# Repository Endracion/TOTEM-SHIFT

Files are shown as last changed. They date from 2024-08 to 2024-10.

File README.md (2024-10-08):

<picture align="center">
  <source media="(prefers-color-scheme: dark)" srcset="/docs/images/TOTEM_logo_dark.svg">
  <source media="(prefers-color-scheme: light)" srcset="/docs/images/TOTEM_logo_bright.svg">
  TOTEM logo
</picture>

<h1 align="center">T O T E M - S H I F T</h1>

TOTEM-SHIFT is a modified 38 keys column-staggered split keyboard originally by GEIGEIGEIST.

This TOTEM-SHIFT version aims to allow for a larger battery and emphasize styling options through a swappable top plate held with magnets ([demo](https://www.youtube.com/watch?v=WX03MpgzbRs)). Meant to be used with a SEEED XIAO BLE (no longer supports the RP2040 with the TRRS port removed) for a wireless only build.

**WHY** a swappable top plate? Well I'm sure everyone has asked themselves at least once, which case should I go for? And then you're half locked into it.
I want to be able to change my mind, to change colors, logos, motifs or other surface effects to go with the style I want that day, so why not allow myself to do just that with a swappable top plate!

It was created for the SEEED XIAO keyboard contest by GEIGEIGEIST.\
[Here](https://www.hackster.io/geist/totem-a-tiny-splitkeyboard-with-splay-cb2e43) you can read about the process of making it.

Note that most of the guides and links will remain unchanged, the major changes will be to the 3D printed case design, as it uses the [TOTOEM Redux by VOID](https://www.printables.com/model/840146-totem-redux) case files as base, which are better suited to FDM 3D printing.

> **Note**
> The PCB is modified enought that this version will not be compatible with existing PCBs or cases for the original TOTEM.

***

## LAYOUT

TOTEM layout

***

## PCB

[Here](/PCB/TOTEM-SHIFT%200.4) you can find the KiCad files and Gerbers for the TOTEM.

Gerber files to upload for production are found [here](https://github.com/Endracion/TOTEM-SHIFT/tree/main/PCB/TOTEM-SHIFT%200.4/production).

***

## CASE

You can use the TOTEM without a case, but [here](https://www.printables.com/model/1033457-totem-shift-wireless-ble-redux-split-splay-keyboar) is the FDM 3D printed case I designed for it.

***

## BUILD GUIDE
  
The build guide for the TOTEM can be found [here](/docs/buildguide.md).

***

## FIRMWARE

[ZMK config](https://github.com/Endracion/zmk-config-totem-shift) for the TOTEM (wireless using the XIAO BLE)

The dongle version is coming at a later time.

***

## PHOTOS

This is the 3D printed TOTEM-SHIFT BLE Redux case with the MOTE keycaps.

This is the TOTEM in a black resin case

TOTEM black resin\
TOTEM black resin\
TOTEM black resin

***

## BUY 

If there is enough interest, I may do a production run for this modified version, please feel free to reach out.

***

## CREDITS

### ORIGINAL CREATOR

The amazing [GEIGEIGEIST](https://github.com/GEIGEIGEIST) whose design are beautiful and inspiring.
VOID who created a FDM optimized case [TOTOEM Redux](https://www.printables.com/model/840146-totem-redux).
eiga for the [MOTE keycaps]{https://www.printables.com/model/864126-mote-choc-low-profile-flat-keycaps}.

### INSPIRATION

The additional pinky key makes the TOTEM compatible with the layout boards like the [Balbuzard](https://github.com/brow/balbuzard) by [Tom Brow](https://github.com/brow) and the [Osprette](https://github.com/smores56/osprette) by [Sam Mohr](https://github.com/smores56) use, where you put the keybinding of the top left and right keys on an outer pinky key.

### HELP FIXING THINGS

People who helped GEIGEIGEIST create this board and fix stuff:

#### PCB
- [Marco "Bob"](https://github.com/GroooveBob)

#### CASE
- [Freya](https://github.com/freya-irl)
- [Bubbleology](https://github.com/bubbleology)

#### FIRMWARE
- [Cem Aksoylar](https://github.com/caksoylar)
- [Grinnie](https://github.com/regicidalplutophage)
- [Alaa Saad Mansour](https://github.com/AlaaSaadAbdo)
- [pekudzu](https://github.com/pekudzu)

If you build a TOTEM, GEIGEIGEIST would be pretty happy to see some pictures. And if you want to leave him a tip you can do so [here](https://ko-fi.com/geigeigeist) (but please don't feel pressured)

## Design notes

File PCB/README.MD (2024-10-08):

# TOTEM-SHIFT PCB FILES

I have modified the original PCB extensively, so here is a list of the largest changes:
- Moved the middle finger column down by approx 2.3mm, as it felt a little high compared to other boards.
- Made the underside of the XIAO easier to solder through a larger cutout.
- Moved the battery contact points above the diodes for the larger size battery cavity.
- Moved the diodes to the rear to make a little more space for the battery and for a clean top PCB.
- Rerouted many traces, cleaned up others and added many diagonal angles for aesthetic purposes and to remove acute angles which are more prone to manufacturing errors.
- Removed the TRRS connector completely as this is a wireless-centric design now.
- Replaced the reset and power switches with hidden ones inside of the top plate, where the TRRS used to be. This gives the case a completely clean look.
- Removed the large color silkscreens as while they were super nice, it was not possible for me to edit them in a way that looked good since I don't have the source files.
- Moved a few other things to make place for these changes.
- Tried to realign one of the holes on the right as it wasn't mirrored properly.
- Everything has been updatd for KiCad 8.0 and gerber files should be able to be easily uploaded to PCB manufacturer websites, I've provided my gerber zip file prepared by JLCPCB's plugin.

> **Note**
> As a reminder: The PCB is modified enought that this version will not be compatible with existing PCBs or cases for the original TOTEM.

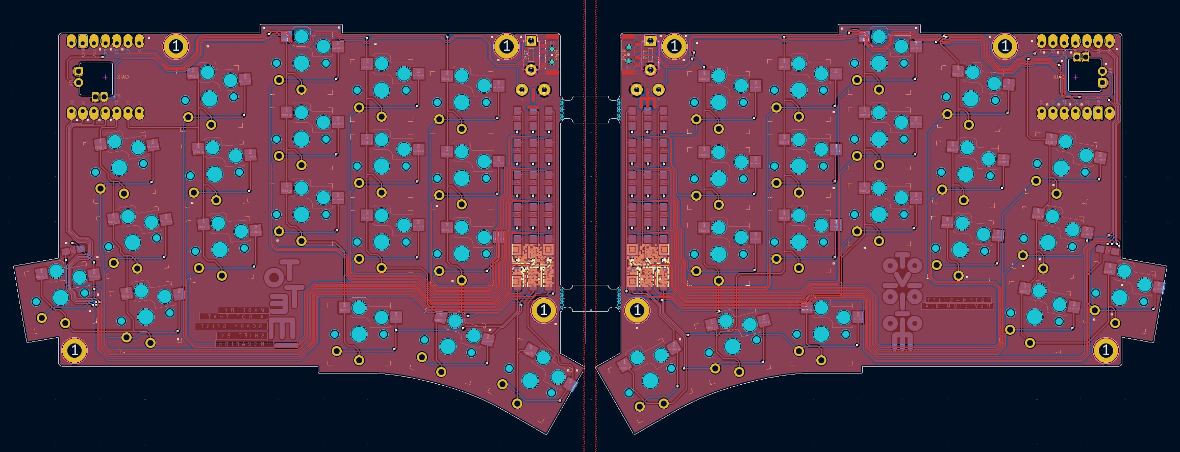
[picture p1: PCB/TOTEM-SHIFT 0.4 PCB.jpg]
TOTEM PCB


# TOTEM-SHIFT FUTURE

What I'm thinking of working on next after this build is complete and I'm satisfied using it.

- [ ] Utilize additional pins from NFC/Sense for ?
- [ ] Implement support for LCD on the board or on the dongle (for layer visibility and style)
- [ ] Implement support for encoder
- [ ] Implement support for pointing device (touchpad, trackpad, mini trackball)
- [ ] Recreate a similar board from scratch that's fully reversible

# TOTEM PCB FILES

## MANUFACTURING
If you want to get the PCB made you need to download the [ZIP](/PCB/totem_0-3/totem_0-3_gerbers.zip/) and upload it to the website of the manufacture 
I can recommend [JLCPCB](https://jlcpcb.com/), [Seeed Fusion](https://www.seeedstudio.com/fusion_pcb.html) or [PCBway](https://www.pcbway.com/).

- Download [the ZIP file](/PCB/TOTEM-SHIFT%200.4/production/TOTEM-SHIFT_split_keyboard_0.4.zip)
- Upload the ZIP file to the website of the manufacturer.
- Sometimes the Gerber preview from JLCPCB can't display the PCB, even when the files are fine. In this case use these dimensions: 258.7mm * 94.35mm.
- PCB Thickness: 1.6mm
- Layers: 2
- Different designs: 2 (because both halves are not the same).
- PCB Qty as much as you like, but minimum is always 5. One PCB is a full keyboard.
- PCB Color Black (or any other color you like).
- No impedance control.
- Surface Finish HASL (with lead) if you want the easiest soldering experience or LeadFree HASL.
- Remove Order Number: Yes

TOTEM PCB

***

## CHECK PINOUT OR TRACES

If you only want to check the traces or see what is connected to which pin you can take a look at these graphics.
You can also take a look at the [schematics](TOTEM_0-3_schematics.pdf) and the [PCB](TOTEM_0-3_PCB.pdf) as PDF.

TOTEM pinout

***

TOTEM traces

***

## TAKE A DEEPER LOOK OR MODIFY 

You can download the project if you need to take a deeper look or modify something. You need the Open Source software [KiCad](https://www.kicad.org/) to open it.

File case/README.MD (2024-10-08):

# TOTEM-SHIFT BLE REDUX CASE

These files can be found on Printables: [TOTEM-SHIFT Wireless BLE Redux Case](https://www.printables.com/model/1033457-totem-shift-wireless-ble-redux-split-splay-keyboar).
I've paired with the [MOTE](https://www.printables.com/model/864126-mote-choc-low-profile-flat-keycaps) keycaps and the [15 degree remix](https://www.printables.com/model/1000549-mote-remixed-choc-low-profile-flat-keycaps-with-mo) for more of a keywell feel.

I remixed the excellent [Totem Redux](https://www.printables.com/model/840146-totem-redux) by VOID and drew inspiration from BeeKeeb's rendition as well.
This case is made to be printed on an FDM printer, though it may work just fine on resin as well, I have not tested it.

My changes are as follows:
- Larger cavity above the diode area to accommodate a larger battery up to approx 7x15x42mm with capacities up to ~180 mAh.
- Removed all holes from the top cover in order to make it look cleaner and allow for future design choices (multi color motifs coming soon).
- Replaced these top screw holes with recessed magnet holes and crush tabs (so they're press fit) so that it can be magnetically attached and swapped ([demo](https://www.youtube.com/watch?v=WX03MpgzbRs)).
- Removed the countersink from the bottom plate so that the midplate is screwed into the bottom plate and acts as the magnet retention mechanism, along with the recessed feet holes as it won't print well on FDM.
- Removed the need for standoffs, everything screws or is pushed directly into the plastic for a tight fit.
- Removed all side holes except USB-C port since the TRRS port is removed and the reset and power switches are now hidden under the top cover.
- Adjusted many small parts of the assembly and redrew the bottom case to make FDM printing easier.
- Adjusted part heights to match 0.2 mm printing layer height and so that the midplate is the correct height to attach the switches to it and not create additional flexing.

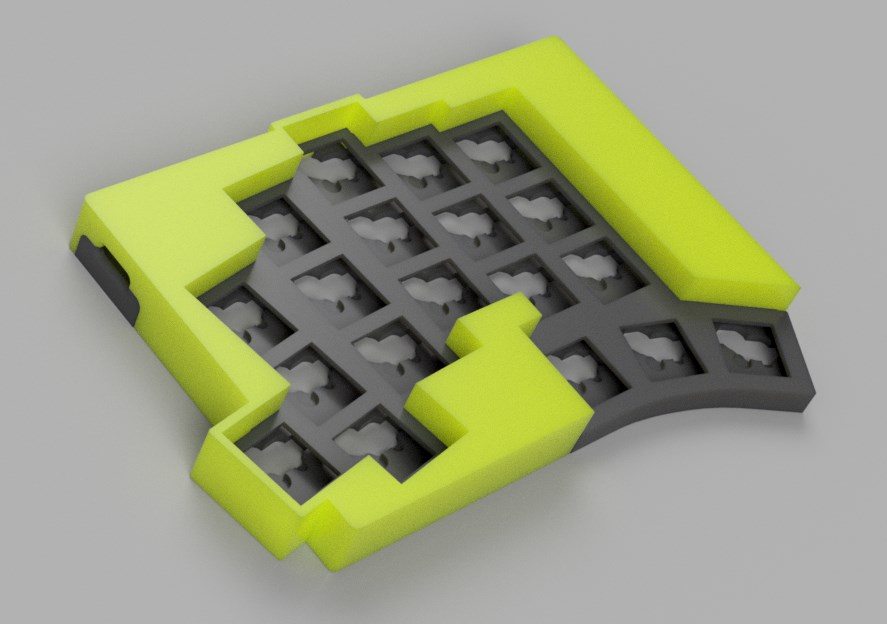
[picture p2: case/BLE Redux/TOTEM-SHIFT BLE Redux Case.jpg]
TOTEM-SHIFT BLE Redux case


# ORIGINAL TOTEM CASE

Each half consists of a bottom and a top part (with an integrated switchplate) and is meant to be 3D printed in resin. 

I got good results from [JLCPCB](https://cart.jlcpcb.com/quote) (15€ + tax and shipping for a black or white version) and [PCBway](https://www.pcbway.com/rapid-prototyping/manufacture/?type=2&reffercode=TOP) (50€ + tax and shipping for a clear case).

Where possible use the STEP files, but the STL files should be fine too.

If you're sure you only will use the wired version you can also use the case without a power switch (USB) or use the case without a TRRS cutout if you plan on using the wireless version (BLE).

> **Note**
> The manufacturer will probably warn you about too thin sections, but it worked fine for me since these sections are pretty small.

TOTEM case

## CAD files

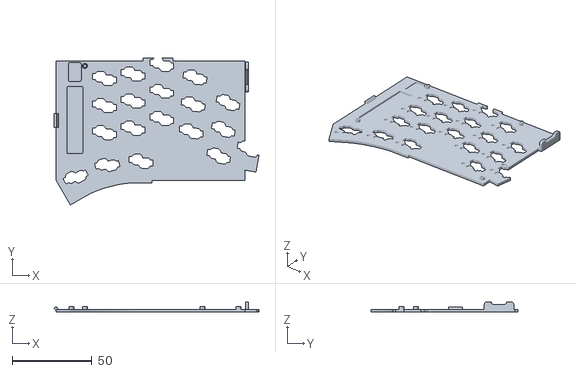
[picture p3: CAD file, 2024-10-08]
case/BLE Redux/TOTEM-SHIFT Right Bottom.stl
128.7 x 92.3 x 6.50

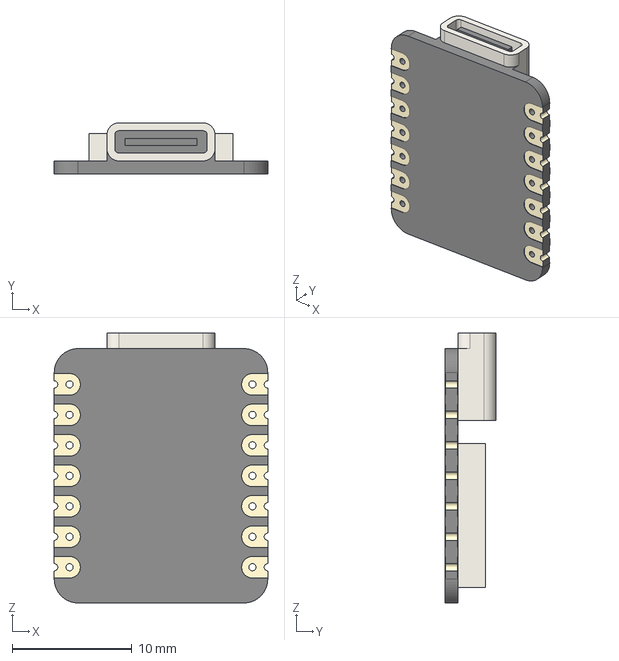
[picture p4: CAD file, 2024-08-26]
PCB/TOTEM-SHIFT 0.4/TOTEM3D/xiao-ble-tht.step
17.8 x 4.27 x 22.5 mm

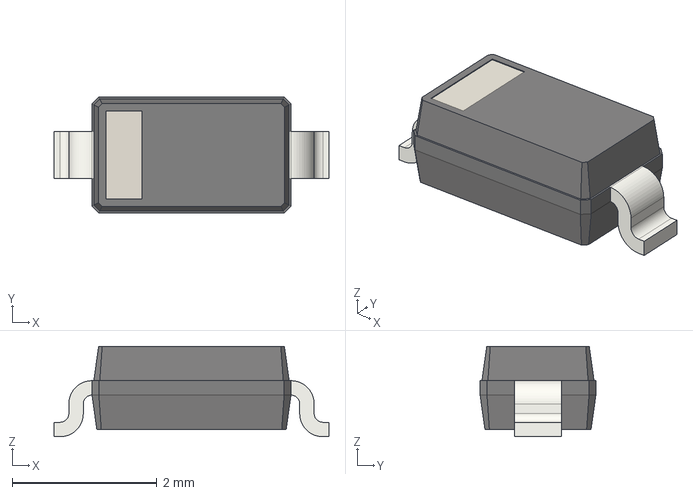
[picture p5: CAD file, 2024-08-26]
PCB/TOTEM-SHIFT 0.4/TOTEM3D/D_SOD-123.step
3.80 x 1.60 x 1.25 mm

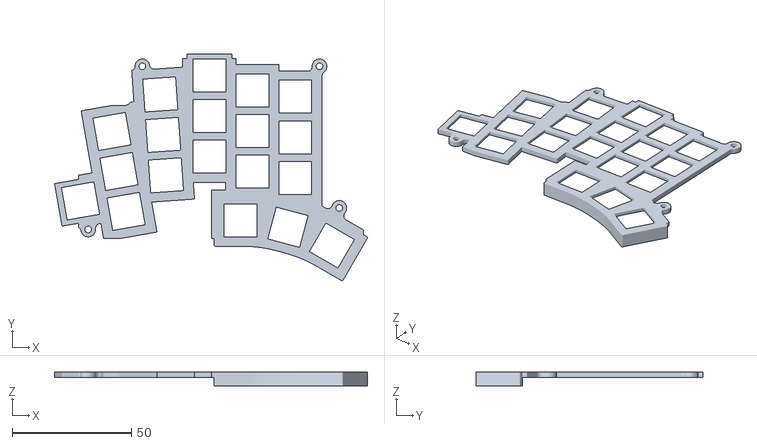
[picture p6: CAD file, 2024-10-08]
case/BLE Redux/TOTEM-SHIFT Left Midplate.stl
131.1 x 94.9 x 5.80

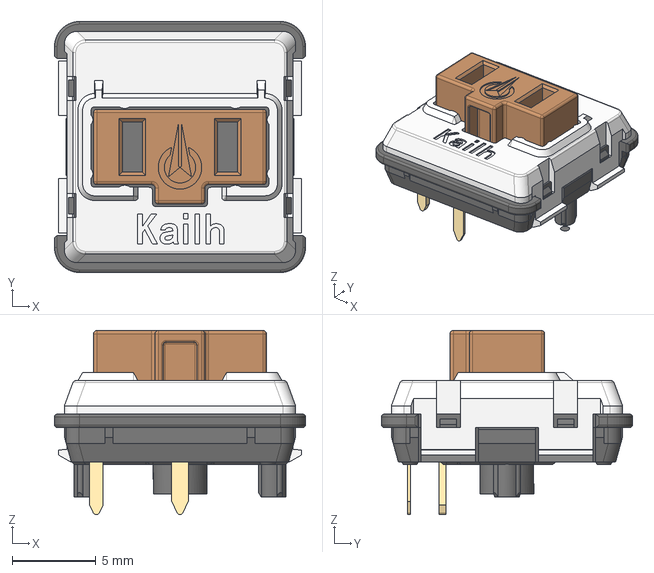
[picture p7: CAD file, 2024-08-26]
PCB/TOTEM-SHIFT 0.4/TOTEM3D/Kailh_switch_PG1350_optional.step
15.0 x 15.0 x 11.0 mm

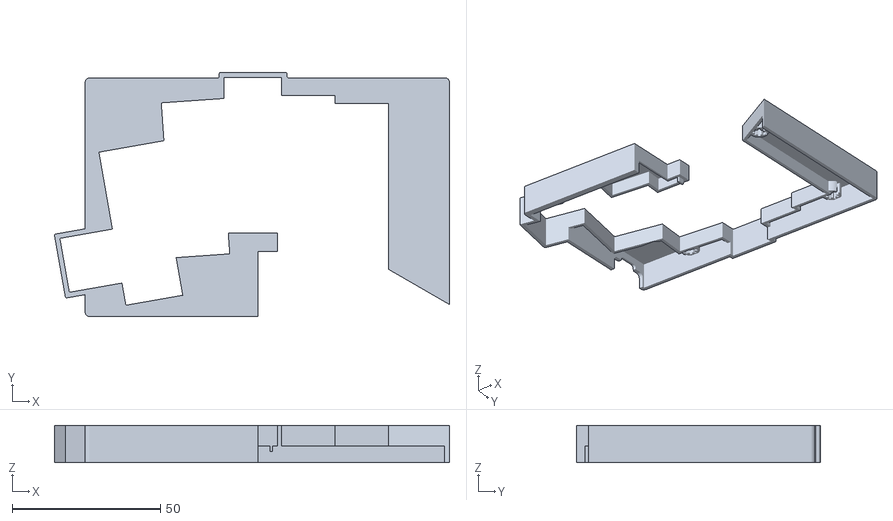
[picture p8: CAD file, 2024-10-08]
case/BLE Redux/TOTEM-SHIFT Left Top Blank.stl
133.4 x 82.5 x 12.6

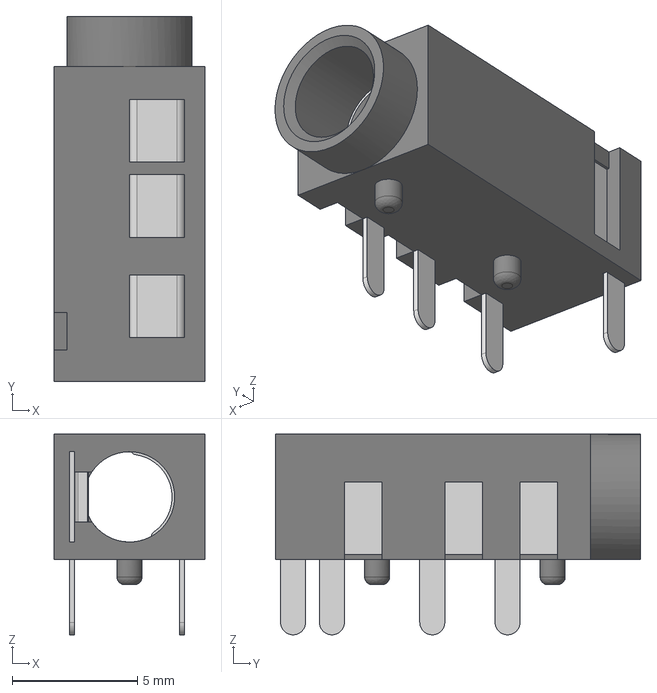
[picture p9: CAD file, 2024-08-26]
PCB/TOTEM-SHIFT 0.4/TOTEM3D/PJ320A.STEP
6.00 x 14.6 x 8.00 mm

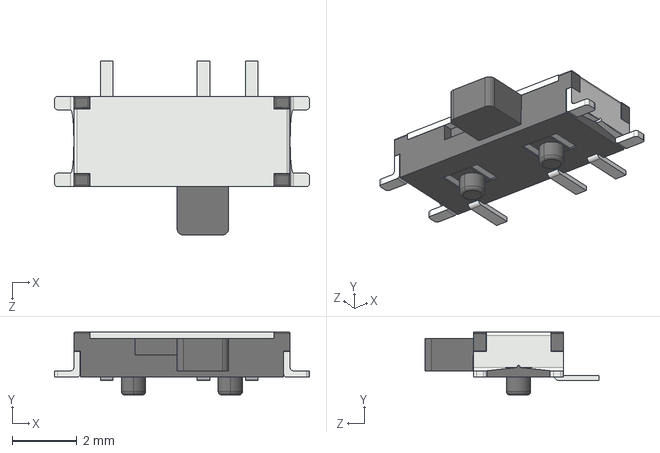
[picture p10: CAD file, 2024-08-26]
PCB/TOTEM-SHIFT 0.4/TOTEM3D/MSK12C02.STEP
7.90 x 1.95 x 5.39 mm

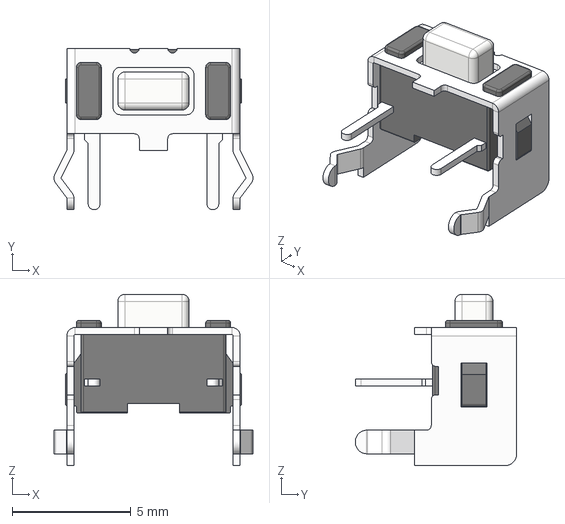
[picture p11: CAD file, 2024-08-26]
PCB/TOTEM-SHIFT 0.4/TOTEM3D/SW_SKHLLC.step
8.38 x 6.80 x 7.22 mm

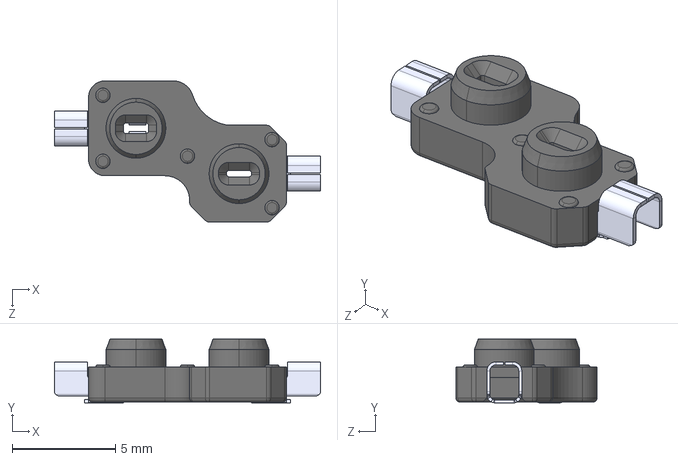
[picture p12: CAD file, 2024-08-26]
PCB/TOTEM-SHIFT 0.4/TOTEM3D/Kailh_socket_PG1350_optional.STEP
12.9 x 3.09 x 6.85 mm
pin x 2
socket

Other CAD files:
case/BLE Redux/TOTEM-SHIFT Left Bottom.stl

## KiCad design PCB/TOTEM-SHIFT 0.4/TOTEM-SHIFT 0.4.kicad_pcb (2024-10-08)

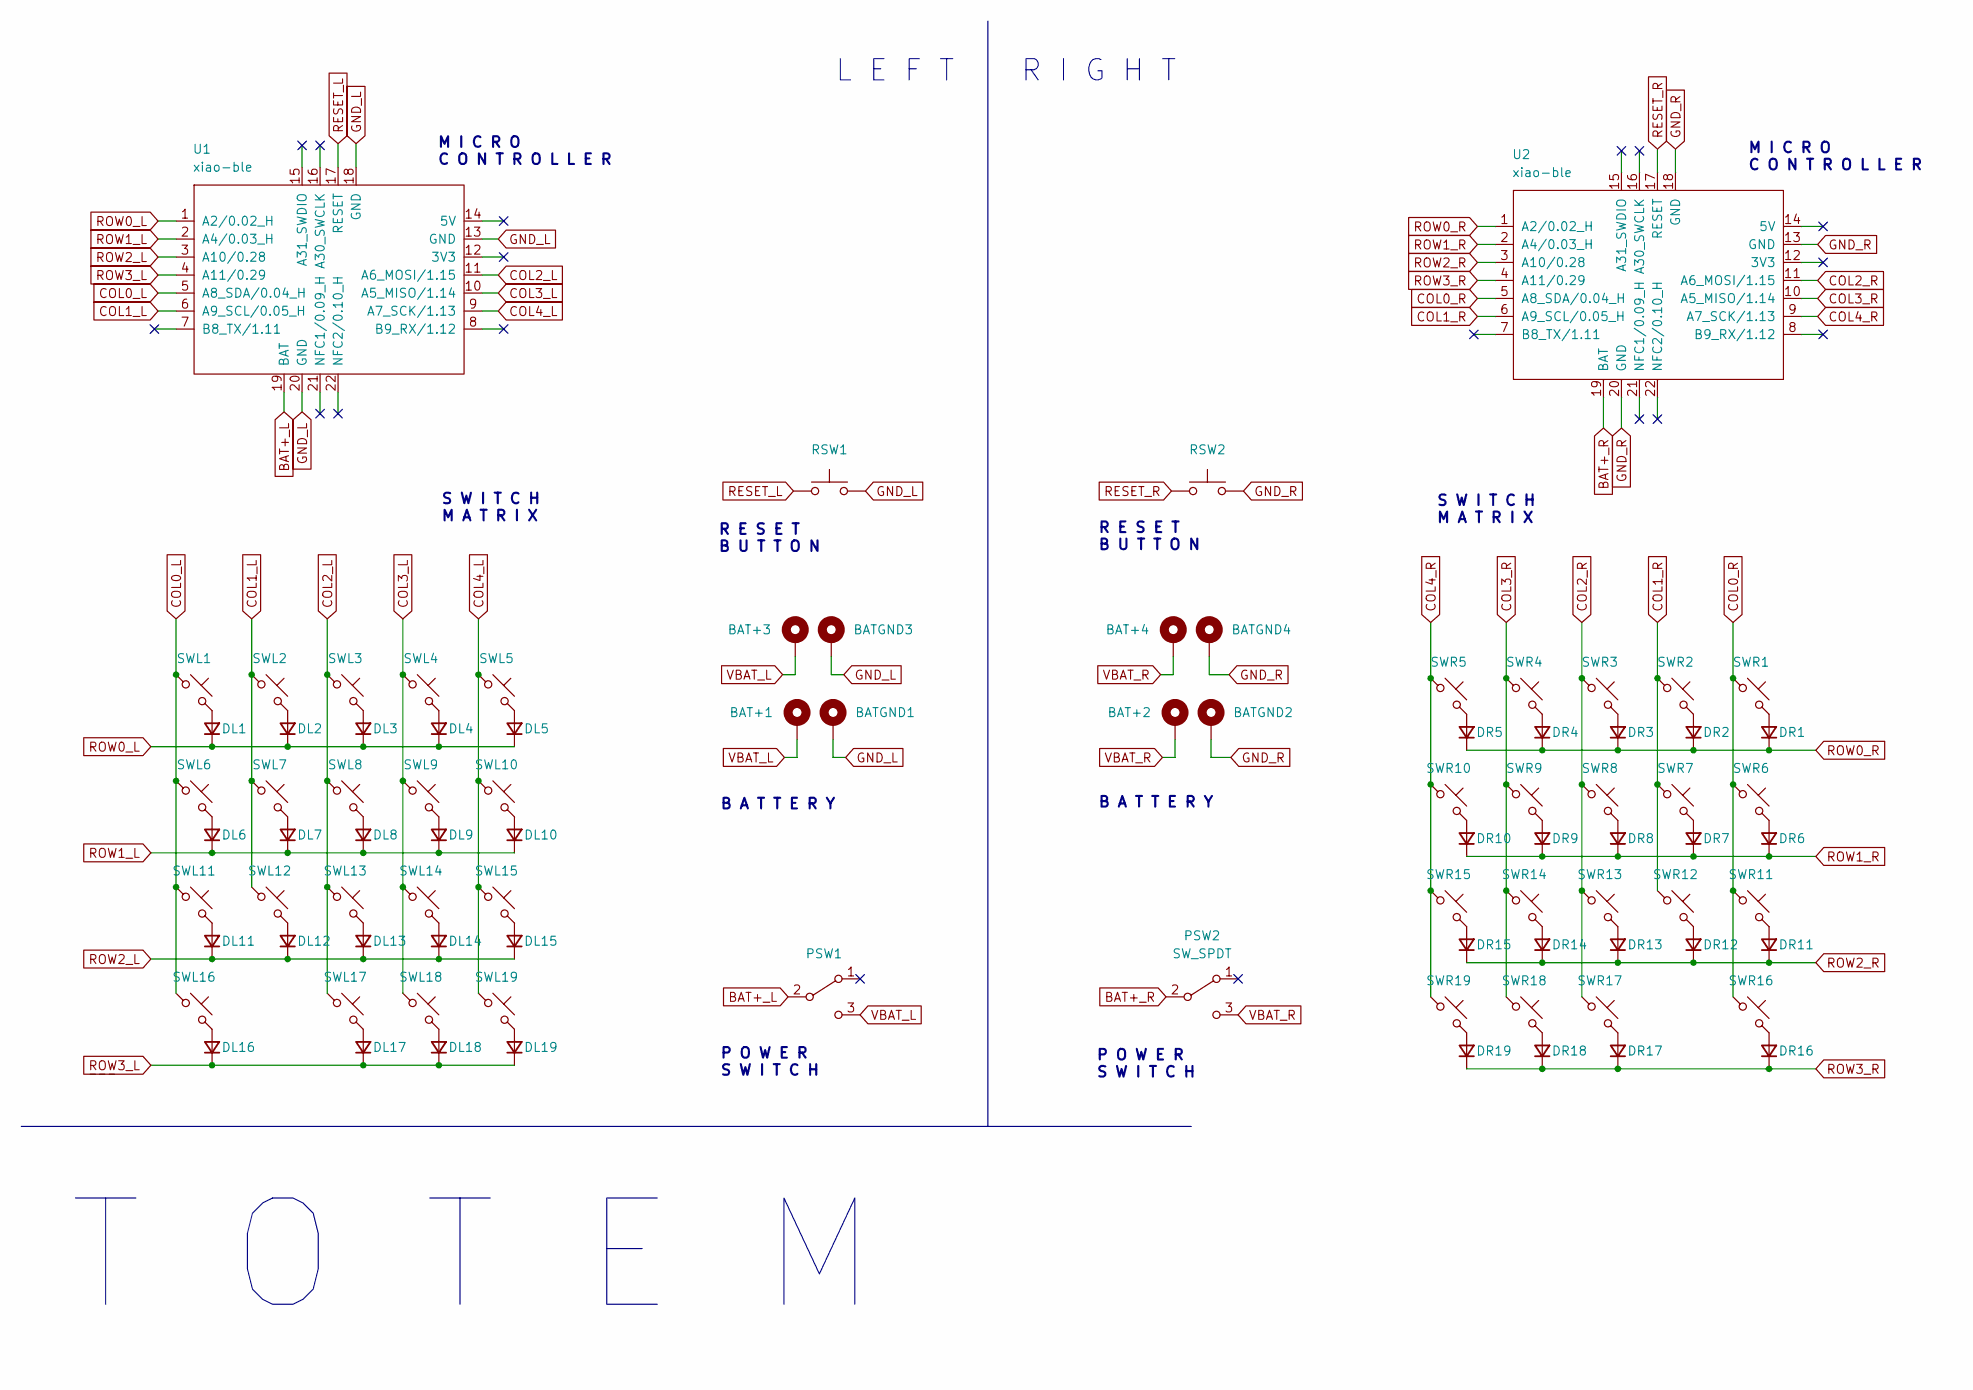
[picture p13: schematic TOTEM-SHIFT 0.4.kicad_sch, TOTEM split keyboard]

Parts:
BAT+1, BAT+2, BAT+3, BAT+4: +; BatteryPad
BATGND1, BATGND2, BATGND3, BATGND4: -; BatteryPad
DL1, DL2, DL3, DL4, DL5, DL6, DL7, DL8, DL9, DL10, DL11, DL12, DL13, DL14, DL15, DL16, DL17, DL18, DL19: D_Small; Diode_SOD123
DR1, DR2, DR3, DR4, DR5, DR6, DR7, DR8, DR9, DR10, DR11, DR12, DR13, DR14, DR15, DR16, DR17, DR18, DR19: D_Small; Diode_SOD123
PSW1, PSW2: SW_SPDT; MSK12C02
RSW1, RSW2: SW_Push; SW_PUSH_1P1T_6x3.5mm_H5.0_APEM_MJTP1250
SWL1, SWL2, SWL3, SWL4, SWL5, SWL6, SWL7, SWL8, SWL9, SWL10, SWL11, SWL12, SWL13, SWL14, SWL15, SWL16, SWL17, SWL18, SWL19: SW_Push_45deg; Kailh_socket_PG1350_optional
SWR1, SWR2, SWR3, SWR4, SWR5, SWR6, SWR7, SWR8, SWR9, SWR10, SWR11, SWR12, SWR13, SWR14, SWR15, SWR16, SWR17, SWR18, SWR19: SW_Push_45deg; Kailh_socket_PG1350_optional
U1, U2: xiao-ble; xiao-ble-smd-cutout

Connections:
BAT+_L: PSW1.2 (B), U1.19 (BAT); also elsewhere on the board
BAT+_R: PSW2.2 (B), U2.19 (BAT); also elsewhere on the board
COL0_L: SWL1.1, SWL6.1, SWL11.1, SWL16.1, U1.5 (A8_SDA/0.04_H)
COL0_R: SWR1.1, SWR6.1, SWR11.1, SWR16.1, U2.5 (A8_SDA/0.04_H)
COL1_L: SWL2.1, SWL7.1, SWL12.1, U1.6 (A9_SCL/0.05_H)
COL1_R: SWR2.1, SWR7.1, SWR12.1, U2.6 (A9_SCL/0.05_H)
COL2_L: SWL3.1, SWL8.1, SWL13.1, SWL17.1, U1.11 (A6_MOSI/1.15)
COL2_R: SWR3.1, SWR8.1, SWR13.1, SWR17.1, U2.11 (A6_MOSI/1.15)
COL3_L: SWL4.1, SWL9.1, SWL14.1, SWL18.1, U1.10 (A5_MISO/1.14)
COL3_R: SWR4.1, SWR9.1, SWR14.1, SWR18.1, U2.10 (A5_MISO/1.14)
COL4_L: SWL5.1, SWL10.1, SWL15.1, SWL19.1, U1.9 (A7_SCK/1.13)
COL4_R: SWR5.1, SWR10.1, SWR15.1, SWR19.1, U2.9 (A7_SCK/1.13)
GND_L: BATGND1.1, BATGND3.1, RSW1.2, U1.13 (GND), U1.18 (GND), U1.20 (GND); also elsewhere on the board
GND_R: BATGND2.1, BATGND4.1, RSW2.2, U2.13 (GND), U2.18 (GND), U2.20 (GND); also elsewhere on the board
unnamed: DL1.2 (A), SWL1.2
unnamed: DL2.2 (A), SWL2.2
unnamed: DL3.2 (A), SWL3.2
unnamed: DL4.2 (A), SWL4.2
unnamed: DL5.2 (A), SWL5.2
unnamed: DL6.2 (A), SWL6.2
unnamed: DL7.2 (A), SWL7.2
unnamed: DL8.2 (A), SWL8.2
unnamed: DL9.2 (A), SWL9.2
unnamed: DL10.2 (A), SWL10.2
unnamed: DL11.2 (A), SWL11.2
unnamed: DL12.2 (A), SWL12.2
unnamed: DL13.2 (A), SWL13.2
unnamed: DL14.2 (A), SWL14.2
unnamed: DL15.2 (A), SWL15.2
unnamed: DL16.2 (A), SWL16.2
unnamed: DL17.2 (A), SWL17.2
unnamed: DL18.2 (A), SWL18.2
unnamed: DL19.2 (A), SWL19.2
unnamed: DR1.2 (A), SWR1.2
unnamed: DR2.2 (A), SWR2.2
unnamed: DR3.2 (A), SWR3.2
unnamed: DR4.2 (A), SWR4.2
unnamed: DR5.2 (A), SWR5.2
unnamed: DR6.2 (A), SWR6.2
unnamed: DR7.2 (A), SWR7.2
unnamed: DR8.2 (A), SWR8.2
unnamed: DR9.2 (A), SWR9.2
unnamed: DR10.2 (A), SWR10.2
unnamed: DR11.2 (A), SWR11.2
unnamed: DR12.2 (A), SWR12.2
unnamed: DR13.2 (A), SWR13.2
unnamed: DR14.2 (A), SWR14.2
unnamed: DR15.2 (A), SWR15.2
unnamed: DR16.2 (A), SWR16.2
unnamed: DR17.2 (A), SWR17.2
unnamed: DR18.2 (A), SWR18.2
unnamed: DR19.2 (A), SWR19.2
RESET_L: RSW1.1, U1.17 (RESET); also elsewhere on the board
RESET_R: RSW2.1, U2.17 (RESET); also elsewhere on the board
ROW0_L: DL1.1 (K), DL2.1 (K), DL3.1 (K), DL4.1 (K), DL5.1 (K), U1.1 (A2/0.02_H)
ROW0_R: DR1.1 (K), DR2.1 (K), DR3.1 (K), DR4.1 (K), DR5.1 (K), U2.1 (A2/0.02_H)
ROW1_L: DL6.1 (K), DL7.1 (K), DL8.1 (K), DL9.1 (K), DL10.1 (K), U1.2 (A4/0.03_H)
ROW1_R: DR6.1 (K), DR7.1 (K), DR8.1 (K), DR9.1 (K), DR10.1 (K), U2.2 (A4/0.03_H)
ROW2_L: DL11.1 (K), DL12.1 (K), DL13.1 (K), DL14.1 (K), DL15.1 (K), U1.3 (A10/0.28)
ROW2_R: DR11.1 (K), DR12.1 (K), DR13.1 (K), DR14.1 (K), DR15.1 (K), U2.3 (A10/0.28)
ROW3_L: DL16.1 (K), DL17.1 (K), DL18.1 (K), DL19.1 (K), U1.4 (A11/0.29)
ROW3_R: DR16.1 (K), DR17.1 (K), DR18.1 (K), DR19.1 (K), U2.4 (A11/0.29)
VBAT_L: BAT+1.1, BAT+3.1, PSW1.3 (C); also elsewhere on the board
VBAT_R: BAT+2.1, BAT+4.1, PSW2.3 (C); also elsewhere on the board
VCC_L: U1.12 (3V3)
VCC_R: U2.12 (3V3)

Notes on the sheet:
M I C R O C O N T R O L L E R
R E S E T B U T T O N
S W I T C H M A T R I X
P O W E R S W I T C H
T O T E M
B A T T E R Y
R I G H T
L E F T

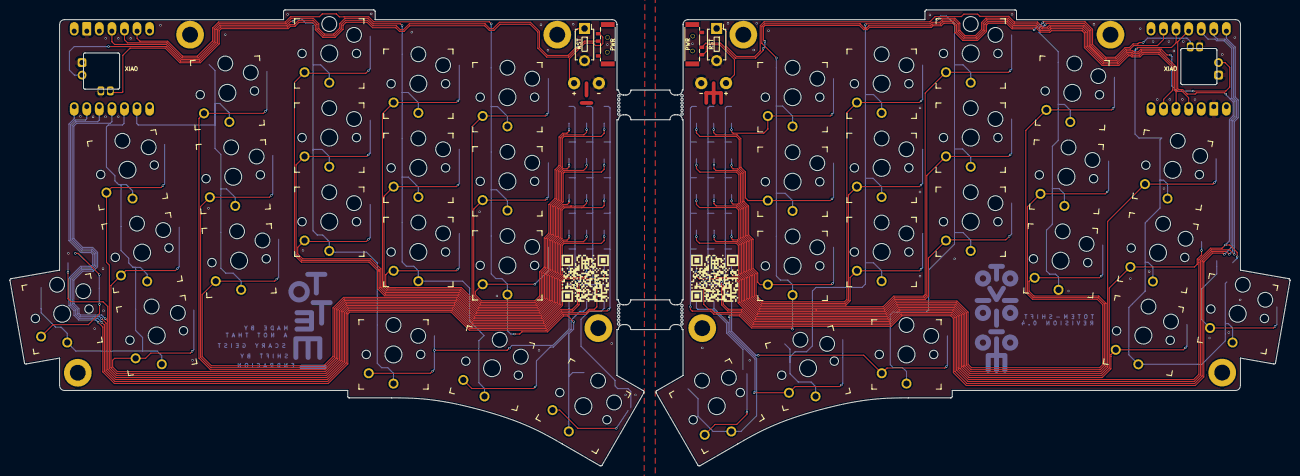
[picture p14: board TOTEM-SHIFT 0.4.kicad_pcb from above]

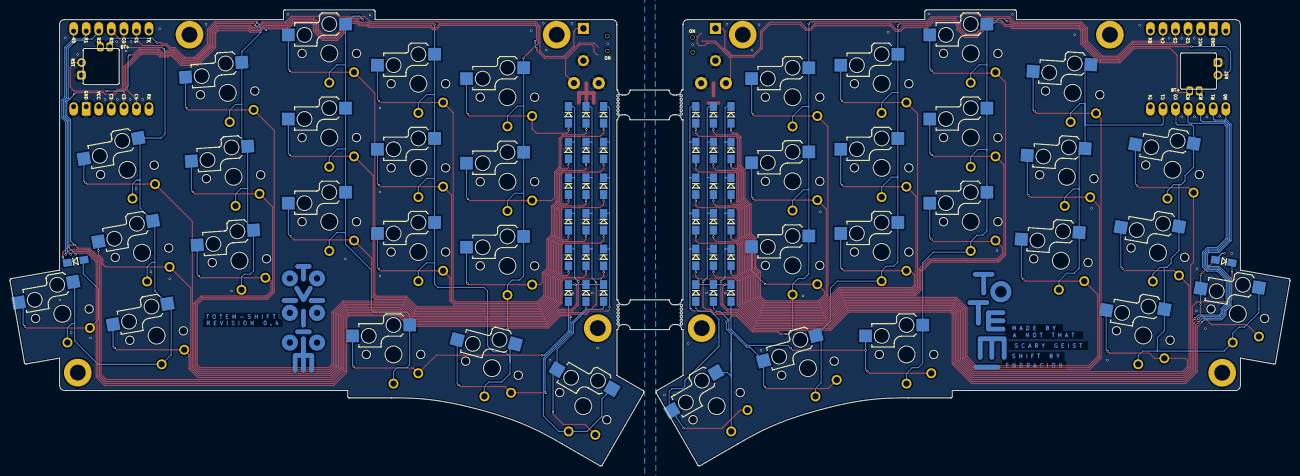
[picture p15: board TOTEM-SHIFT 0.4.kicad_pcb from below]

Board: 2 copper layers, 258.7 x 92.2 mm, 86 parts (38 on the bottom side), 64 nets.

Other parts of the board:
PWR: SW_SPDT; MSK12C02
PWR#2: SW_SPDT; MSK12C02
RST: SW_Push; SW_PUSH_1P1T_6x3.5mm_H5.0_APEM_MJTP1250
RST#2: SW_Push; SW_PUSH_1P1T_6x3.5mm_H5.0_APEM_MJTP1250

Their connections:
BAT+_L: PWR.2 (B); also elsewhere on the board
BAT+_R: PWR#2.2 (B); also elsewhere on the board
GND_L: RST.2; also elsewhere on the board
GND_R: RST#2.2; also elsewhere on the board
RESET_L: RST.1; also elsewhere on the board
RESET_R: RST#2.1; also elsewhere on the board
VBAT_L: PWR.3 (C); also elsewhere on the board
VBAT_R: PWR#2.3 (C); also elsewhere on the board

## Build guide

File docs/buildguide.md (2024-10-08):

# TOTEM BUILD GUIDE

> **Warning**
> The updated build guide is still missing a few pictures.

## PART LIST

### REQUIRED PARTS

| Part name | Count | Remarks | 
| :--- | :---: | :--- |
| TOTEM PCB | 01 | You can find the files for it [here](/PCB//TOTEM-SHIFT%200.4) |
| Seeed XIAO BLE  | 02 | Uses nRF52840 chipset. The best place to get them is direct from SEEED; suggesting the [3 pack wtih free shipping](https://www.seeedstudio.com/Seeed-Studio-XIAO-nRF52840-3PCS-p-5921.html). |
| Choc key switch | 38 | Kailh Choc low profile key switches |
| diodes 1N4148W  | 38 | These are surface mount diodes in SOD123 package |
| 1u Choc keycaps | 38 | GEIST recommends MBK, LDSA or CFX keycaps, but I used the [MOTE](https://www.printables.com/model/864126-mote-choc-low-profile-flat-keycaps/remixes) and the [15 degree remix](https://www.printables.com/model/1000549-mote-remixed-choc-low-profile-flat-keycaps-with-mo) for a keywell feeling |
| reset button | 02 | 3x6x4.3mm DIP 2 pin tacticle switches |
| power switch | 02 | MSK-12C02 |
| Lipo battery | 02 | There is space for a battery of 7x15x42mm with capacities up to ~180 mAh; I used 401230 |
| USB-C cable | 01 | For charging the keyboard or connecting it to your PC |

### OPTIONAL PARTS

| Part name | Count | Remarks | 
| :--- | :---: | :--- |
| switch socket | 38 | Switch sockets for Kailh low-profile choc switches |

### 3DP CASE PARTS

| Part name | Count | Remarks | 
| :--- | :---: | :--- |
| 3D printed case | 02 | Find the case files [here](https://www.printables.com/model/1033457-totem-shift-wireless-ble-redux-split-splay-keyboare) |
| 4mm M2 hex head screws | 08 | The hex head is important, and the material needs to be ferrous so that the magnets can attach to them. |
| 4x2mm round magnets | 08 | These will align with the round screws to magnetically atttach the top plate |
| rubber feet | 08 | Any size you prefer |

## INTRODUCTION

Here is an overview of where and on which side each component needs to be soldered (click on the image to see a larger version).

TOTEM solder guide

***

## BREAK OFF HALVES

The PCB comes in one piece. You need to break it into two halves.

TOTEM PCB

After breaking them apart, you're left with some sprue marks, which you can remove with a file if you like, but you don't need to.

> **Warning**
> You should wear a mask in a well ventilated area while doing this since the FR4 dust is extremely toxic.

PCB sprue marks

I paint the edges black using a sharpie, so they fit better with the top and bottom, but that's optional too.

PCB edges

***

## DIODES

The diodes need to be soldered on the top of the PCB. Pay attention to their orientation:  They have a small line on one side, which should be on the side the arrow on the PCB is facing to.

<p align="center">
<picture>
  <source media="(prefers-color-scheme: dark)" srcset="/docs/images/buildguide/diodes_dark.svg">
  <source media="(prefers-color-scheme: light)" srcset="/docs/images/buildguide/diodes_bright.svg">
  diode orientation
</picture>
</p>

Apply a small amount of solder on one pad.

Solder on one pad

Then use tweezers to place the diode on the pads and reheat the solder to secure the diode.

Solder diode

Now you can solder the second pad.

***
 
## SWITCH SOCKETS (optional)

Here you can apply the same technique as used for the diodes: Apply some solder on one of the pads first.

switch sockets pad

Then place the switch socket in the silk screen markings. The orientation matters here too. Especially if you plan on using the case.

<p align="center">
<picture>
  <source media="(prefers-color-scheme: dark)" srcset="/docs/images/buildguide/socket_dark.svg">
  <source media="(prefers-color-scheme: light)" srcset="/docs/images/buildguide/socket_bright.svg">
  hotswap socket orientation
</picture>
</p>

hotswap socket right and wrong orientation

Then reheat the solder. 
Apply some pressure with a pair of tweezers to make sure the socket is fully seated.\
Now solder the second pad.

switch socket soldered

***

## POWER SWITCHES

Apply a tiny bit of solder on the bigger, outer pads on top of the PCB. 

power switch pads

The power switch has some tiny knobs on its bottom, which fit into the PCB holes. Hold it in place with tweezers and then reheat the solder on the pad. After this, you can solder the other pad and the three pins.

power switch

***

## RESET SWITCHES

Insert the switch into the top of the PCB; aligne it so that it sits straight. Due to the leg shape, it should hold by itself, so you can then solder one leg at a time from the top.

I then turn the board over and use flush cutters to cut part of the producting legs off and add a little more solder from this side.

reset switch

***

## MICROCONTROLLER

> **Warning**
> First flash the microcontroller to make sure it works, before soldering it in. Especially since you can't use sockets for easy removal.

Place the microcontroller in its place. I used the headers they came with, and removed the last pin. This way, the XIAO is perfectly aligned and I can solder the last 2 unconnected pins while making sure everything stays flate.

Afterwards, you can remove the headers and continue soldering each pad.

> **Note**
> Make sure it sits flat on the PCB. Otherwise, the case won't fit.

Apply some flux and try to hold the iron at an angle where you touch the pads of the microcontroller and the PCB while adding solder.

soldering MCU

The pads on the back are a bit harder to solder, but I believe in you! I've made the cutout a lot larger than the original, so it should be a little easier. Apply the same technique as on the front: Try to touch the pads on the microcontroller and the PCB before adding solder. 

First off, if you didn't choose castellated half holes (which I'm too cheap for), you'll have extra pieces of copper in these half holes from the routing step, which you'll need to carefully wedge out and remove. Here I used a needle to push it away from the hole, then some fine tweezers to rock it side to side carefully, so that it detaches without ripping anything. This way you're left with a nice solderable surface.

soldering MCU back

***

## BATTERY

> **Warning**
> Before attaching the battery in any way to the PCB set the power switch to off (right on both sides).

You can see which cable needs to go in which eye by the silkscreen below the eyes. Red is + / Black is -. Do make sure your manufacturer respected this. The red wire is usually isolated with tape or something similar when being shipped.

battery face

Attach the wires of the battery to the pads and solder them in.

Ouch

***

## CLEANING

You can use an old toothbrush, some cotton swabs and some isopropyl (closest to 99% is best) to clean it from flux residues. 

***

## FIRMWARE

If you have not already flashed the firmware to the microcontroller you should do it now.\
[Here](https://github.com/Endracion/zmk-config-totem-shift) you can find the ZMK firmware for the TOTEM.\

Probably a good idea to also install switches to make sure all of them work, before inserting the board into the case.

PCB with switches

***

## CASE

First, place the PCB on the bottom plate, making sure the integrated standoffs go through the holes and fits snugly.

Next, loosely screw in the midplate with the M2 screws straight into the bottom plate. At this step you'll want to push in a few switches so that they clip into the midplate and align it properly.

I placed 5 (corners and middle) for this purpose, and then finished tightening the screws (careful not to overtighten though, it just needs to be finger tight, don't snap the plastic).

My case doesn't have specific locations for the rubber feet if you're installing them, so choose where you'd like to place them.

Next we move on to the top case. The magnet holes are fitted with crush tabs, which allow for different printer tolerances. You will have to push in these magnets into the bottom with a bit of force. I like to place them on the tip of my pliers and push down. Note that there is a little indentation below that allows you to pry the magnet out if anything happens or it doesn't go in straight.

You may have to trim the sides of this little tab in the middle of the plate, but only very slightly at a time, and check for the fit, as you want it to be friction fit when you press down on it, but still allow for it to be removable.

***

## FINAL BUILD

This is what the final keyboard will probably look like. 

final build

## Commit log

2024-08-26 v0.4 Modifications
    [D_SOD-123.step, Kailh_socket_PG1350_optional.STEP, Kailh_switch_PG1350_optional.step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]
2024-08-26 Added TOTEM-SHIFT Redux STLs
    [totem-shift_ble_left_bottom.stl, totem-shift_left_midplate.stl, totem_ble_left_top_no_logo.stl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]
2024-08-26 Corrected case readme
2024-08-26 Update PCB readme
2024-09-02 Testing Hidden Power Switch
    [TOTEM-SHIFT 0.4.kicad_pcb, TOTEM-SHIFT 0.4.kicad_pcb_hiddenpower.kicad_pcb, totem-shift_ble_left_bottom.stl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]
2024-09-02 Small PCB trace fixes
    [TOTEM-SHIFT 0.4.kicad_pcb]
2024-09-04 Major changes, hidden switches and case redesign
    [TOTEM-SHIFT 0.4.kicad_pcb, TOTEM-SHIFT 0.4.kicad_pcb_hiddenpower.kicad_pcb, TOTEM-SHIFT 0.4.kicad_sch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]
2024-10-08 PCB ready for production update
    [TOTEM-SHIFT 0.4.kicad_pcb]
2024-10-08 Reorganized readmes and case
    [TOTEM-SHIFT Left Bottom.stl, TOTEM-SHIFT Left Midplate.stl, TOTEM-SHIFT Left Top Blank.stl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]
2024-10-08 v8 Case
    [TOTEM-SHIFT Left Bottom.stl, TOTEM-SHIFT Right Bottom.stl]
